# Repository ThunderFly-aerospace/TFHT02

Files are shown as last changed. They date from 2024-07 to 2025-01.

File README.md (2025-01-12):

# TFHT02 - Miniature UAV Humidity and Temperature Sensor



The TFHT02 hygrometer sensor offers flexible integration options. It can be directly connected to a Pixhawk autopilot with PX4 firmware, or it can be used as a sensor for the [TF-ATMON monitoring system](https://www.thunderfly.cz/tf-atmon.html). The TFHT02 is optimized for fast response and reduced sensitivity to solar radiation, making it suitable for meteorological measurements of atmospheric profiles, where rapid environmental changes require fast response to maintain high measurement accuracy.

### Atmospheric sounding

The TFHT02 sensor is designed for [direct atmospheric sounding](https://en.wikipedia.org/wiki/Atmospheric_sounding). Here is an example of measured data taken by [TF-G2 autogyro](https://www.thunderfly.cz/tf-g2.html).

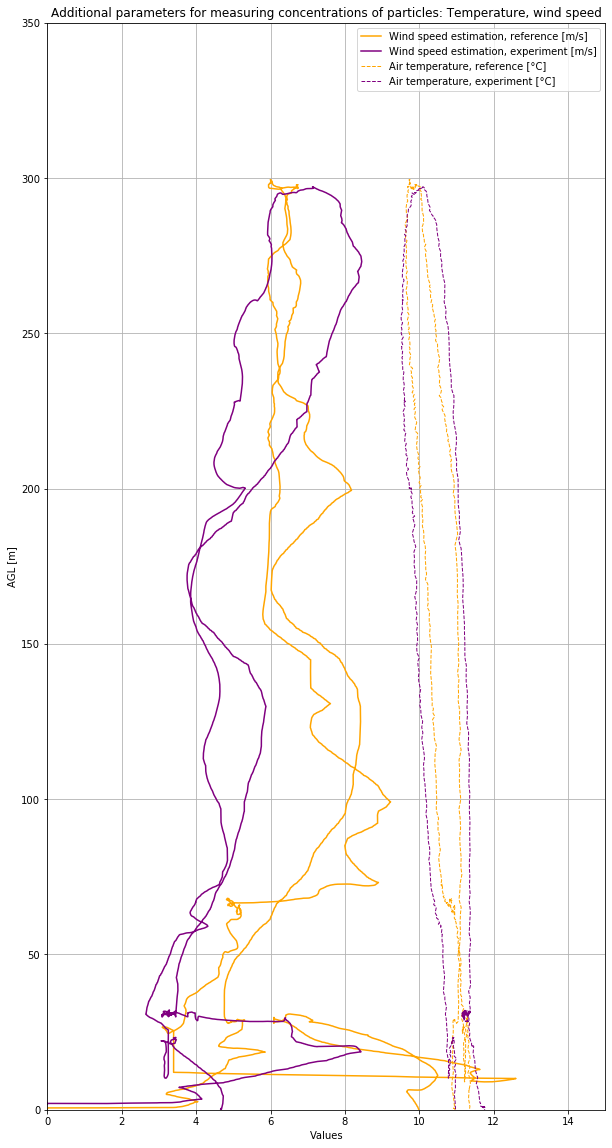
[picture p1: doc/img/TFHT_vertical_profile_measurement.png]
TFHT02A atmospheric profiling


## Where to get it?

The TFHT02 is commercially available from [ThunderFly s.r.o.](https://www.thunderfly.cz/). For a commercial quotation or support, contact us by email at sale@thunderfly.cz or shop at [Tindie store](https://www.tindie.com/products/thunderfly/tfht01-aerial-hygrometer-and-thermometer/).

## Parameters

| Parameter | Value | Description |
|---|---|---|
| Sensing element | [SHT45](https://sensirion.com/media/documents/33FD6951/662A593A/HT_DS_Datasheet_SHT4x.pdf) | Other possible sensors are SHT40 or SHT41 |
| Typical accuracy | 1 %RH and 0.1 °C | |
| Repeatability | 0.15 %RH , 0.08 °C | The stated repeatability is 3 times the standard deviation (3σ) of multiple consecutive measurements at constant ambient conditions. |
| Operating temperature range| 0 °C - +65 °C | Sensor physically measures in range -40°C to +120°C with reduced accuracy |
| Operating humidity range| 0-100 % | At humidity above 80% the performance of the sensor could be degraded in case of prolonged periods |
| I2C connector | 4-pin JST-GH | The second connector could be installed on the opposite side |
| I2C address | 0x44 | |
| Storage temperature range| -20 °C - +40 °C |  |
| Operational input voltage | 3.6 - 5.4V | Overvoltage is internally protected by zener diode |
| Mass | 2 g | PCB without cabling |
| Dimensions | 30 x 15 x 6.5 mm |  PCB |
| Weather resistance | IP40 | External connectors fully occupied. |

## Sensor Design

The TFHT02 sensor is designed with an emphasis on fast response time and minimal sensitivity to solar radiation. This is achieved by reducing the thermal mass around the sensing element, allowing it to rapidly react to changes in ambient conditions. Additionally, the sensor is positioned in a way that maximizes its contact surface with the surrounding airflow, ensuring efficient heat exchange and accurate real-time measurements, which are critical for meteorological applications, especially for atmospheric profiling.

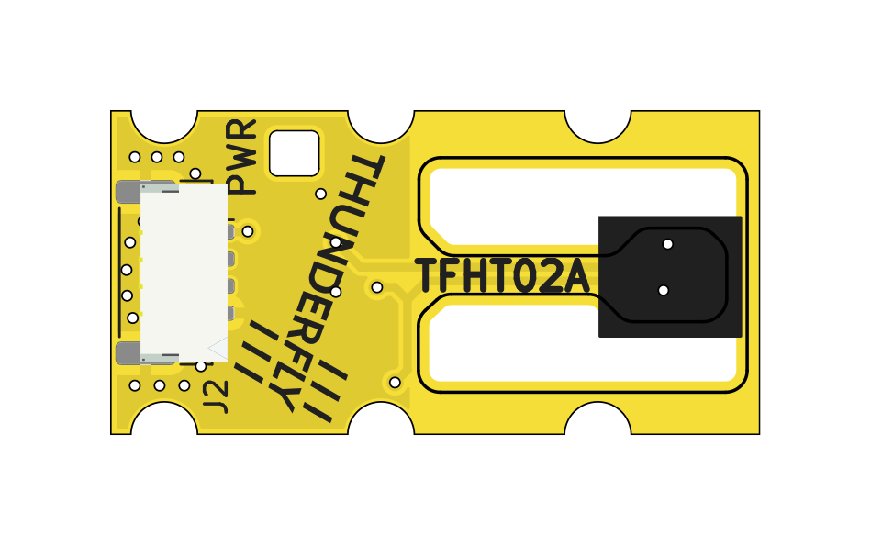
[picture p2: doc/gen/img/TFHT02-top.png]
TFHT02A top view


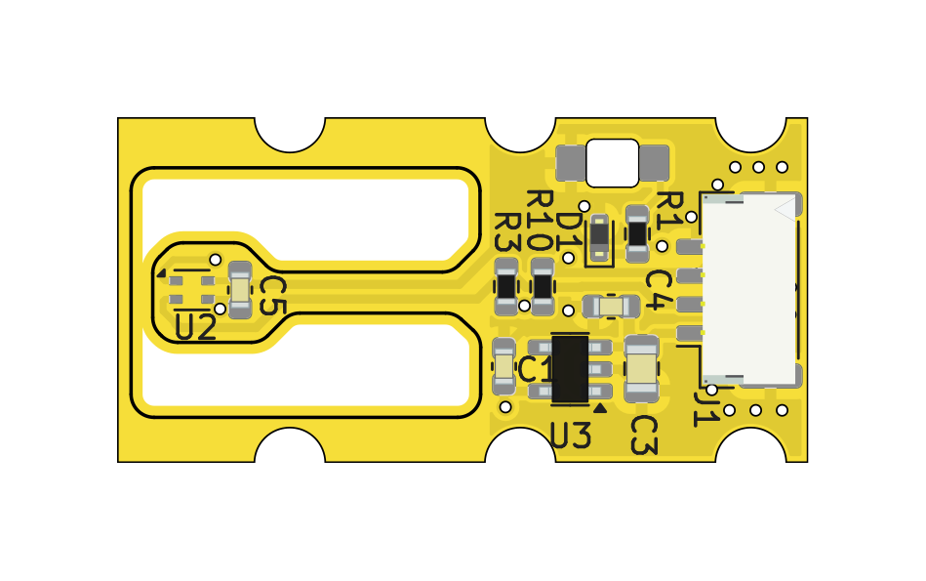
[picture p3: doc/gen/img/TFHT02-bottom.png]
TFHT02A bottom view


### Schematics

Schematics

## Usage in PX4 autopilot firmware

The PX4 autopilot firmware supports the sensor. Multiple sensors can be connected to one autopilot. The measured data could be sent to the ground station and at the same time logged in the onboard ulog file. Sensor support can be enabled by setting the [SENS_EN_SHT4X](http://docs.px4.io/master/en/advanced_config/parameter_reference.html#SENS_EN_SHT3X) parameter to 1.

### Driver Commands Examples

CLI usage example:

    sht4x start -X

Start the sensor driver on the external bus

    sht4x status

Print driver status

    sht4x values

Print the last measured values

    sht4x reset

Reinitialize senzor, reset flags

### PX4 Driver Usage

```
sht4x <command> [arguments...]
 Commands:
   start
     [-I]        Internal I2C bus(es)
     [-X]        External I2C bus(es)
     [-b <val>]  board-specific bus (default=all) (external SPI: n-th bus
                 (default=1))
     [-f <val>]  bus frequency in kHz
     [-q]        quiet startup (no message if no device found)
     [-a <val>]  I2C address
                 default: 68
     [-k]        If initialization (probing) fails, keep retrying periodically

   stop

   status        print status info

   values        Print actual data

   reset         Reinitialize sensor
```

## Usage in Ardupilot firmware

In the Ardupilot firmware, the corresponding sht4x driver for TFHT02 is currently missing. The contributions are welcomed.

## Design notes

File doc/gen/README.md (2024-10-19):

# PCB

Board size: 30.0x15.0 mm (1.18x0.59 inches)

- This is the size of the rectangle that contains the board
- Thickness: 0.89 mm (35 mils)
- Material: FR4
- Finish: HAL lead-free
- Layers: 2
- Copper thickness: 35 µm

Solder mask: TOP / BOTTOM

- Color: Green

Silk screen: TOP / BOTTOM

- Color: White

Stackup:

| Name | Type | Color | Thickness [µm]| Material | Er | Loss tan |
|---|---|---|---|---|---|---|
| F.SilkS | Top Silk Screen | | | | | |
| F.Paste | Top Solder Paste | | | | | |
| F.Mask | Top Solder Mask | Green | 10 | | | |
| F.Cu | copper | | 35 | | | |
| dielectric 1 | core | | 800 | FR4 | 4.5 | 0.020 |
| B.Cu | copper | | 35 | | | |
| B.Mask | Bottom Solder Mask | Green | 10 | | | |
| B.Paste | Bottom Solder Paste  | | | | | |
| B.SilkS | Bottom Silk Screen | | | | | |

# Important sizes

Clearance: 0.2 mm (8 mils)

Track width: 0.3 mm (12 mils)

- By design rules: 0.15 mm (6 mils)

Drill: 0.5 mm (20 mils)

- Vias: 0.5 mm (20 mils) [Design: 0.4 mm (16 mils)]
- Pads: 3.0 mm (118 mils)
- The above values are real drill sizes, they add 0.1 mm (4 mils) to plated holes (PTH)

Via: 0.8/0.4 mm (31/16 mils)

- By design rules: 0.4/0.3 mm (16/12 mils)
- Micro via: yes [0.2/0.1 mm (8/4 mils)]
- Buried/blind via: yes
- Total: 27 (thru: 27 buried/blind: 0 micro: 0)

Outer Annular Ring: 0.15 mm (6 mils)

- By design rules: N/A mm (N/A mils)

Eurocircuits class: 4B
- Using min drill 0.5 mm for an OAR of 0.15 mm

# General stats

Components count: (SMD/THT)

- Top: 1/6 (SMD + THT)
- Bottom: 12/0 (SMD)

Defined tracks:

- 0.3 mm (12 mils)
- 0.4 mm (16 mils)
- 0.5 mm (20 mils)
- 1.0 mm (39 mils)

Used tracks:

- 0.3 mm (12 mils) (15) defined: yes
- 0.4 mm (16 mils) (75) defined: yes
- 0.5 mm (20 mils) (12) defined: yes

Defined vias:

Used vias:

- 0.8/0.4 mm (31/16 mils) (Count: 27, Aspect: 1.1 A) defined: no

Holes (excluding vias):

- 3.0 mm (118 mils) (6)

Oval holes:

Drill tools (including vias and computing adjusts and rounding):

- 0.5 mm (20 mils) (27)
- 3.0 mm (118 mils) (6)

Solder paste stats:

Using a paste with 87.75 % alloy, that has an specific gravity for the alloy of 7.4 g/cm³
and 1.0 g/cm³ for the flux. This paste has an specific gravity of  4.15 g/cm³.

The stencil thickness is  0.12 mm.

| Side | Pads with paste | Area [mm²] | Paste [g] |
|---|---|---|---|
| Top | 6 | 9.28 | 0.05 |
| Bottom | 33 | 30.21 | 0.15 |
| Total  | 39 | 39.48 | 0.20 |

Note: this is just an approximation to the theoretical value. Margins of the solder mask and waste aren't computed.

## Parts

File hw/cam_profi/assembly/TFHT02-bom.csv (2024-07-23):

Component | Description | Part | References | Value | Footprint | Quantity Per PCB | Datasheet | ust_id
1 | Unpolarized capacitor | C | C4C5 | 100nF | C_0603_1608Metric | 2 | ~ | 5c70984812875079b91f8bf2
2 | Unpolarized capacitor | C | C1 | 1uF | C_0603_1608Metric | 1 | ~ | 5c70984812875079b91f8bc2
3 | Unpolarized capacitor | C | C3 | 10uF | C_0805_2012Metric | 1 | ~ | 5c70984812875079b91f8bbd
4 |  | D_ZENER | D1 | BZX585-B5V6.115 | D_SOD-523 | 1 |  | 60879d38128750769ee58e48
5 | Light emitting diode | LED | D2 | LED GREEN | LED_1206_mill | 1 | ~ | 5c70984412875079b91f8895
6 |  | SM04B-GHS-TB | J1J2 | SM04B-GHS-TB | JST_GH_SM04B-GHS-TB_1x04-1MP_P1.25mm_Horizontal | 2 |  | 5c86273d1287500b4e0280be
7 | Resistor | R | R1 | 1k | R_0603_1608Metric | 1 | ~ | 5c70984512875079b91f8957
8 | Resistor | R | R3R10 | 10k | R_0603_1608Metric | 2 | ~ | 5c70984512875079b91f8962
9 | 300mA Low-dropout Voltage Regulator, Vout 3.3V, Vin up to 5.5V, SOT-23 | MIC5504-3.3YM5 | U3 | MIC5504-3.3YM5 | SOT-23-5 | 1 | http://ww1.microchip.com/downloads/en/DeviceDoc/MIC550X.pdf | 5c7255e81287500b4e112ea2
10 | Digital Humidity and Temperature Sensor, +/-1%RH, +/-0.1degC, I2C, 1.08-3.6V, 16bit, DFN-4 | SHT4x | U2 | SHT4x | Sensirion_DFN-4_1.5x1.5mm_P0.8mm_SHT4x_NoCentralPad | 1 | https://www.tme.eu/Document/c90a92e7875700dbf5278abff1cc96dc/SHT4x.pdf | 65227831462c6d9e720559a1

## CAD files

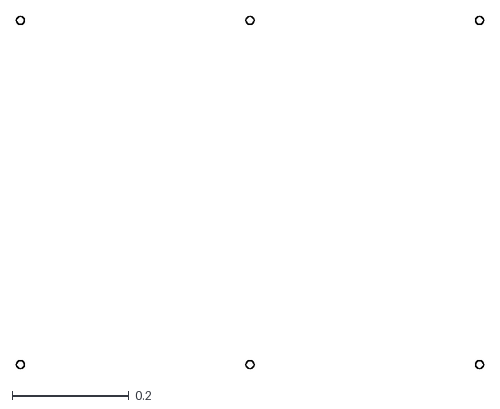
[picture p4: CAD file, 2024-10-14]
doc/gen/dxf/TFHT02-Margin.dxf
0.801 x 0.604

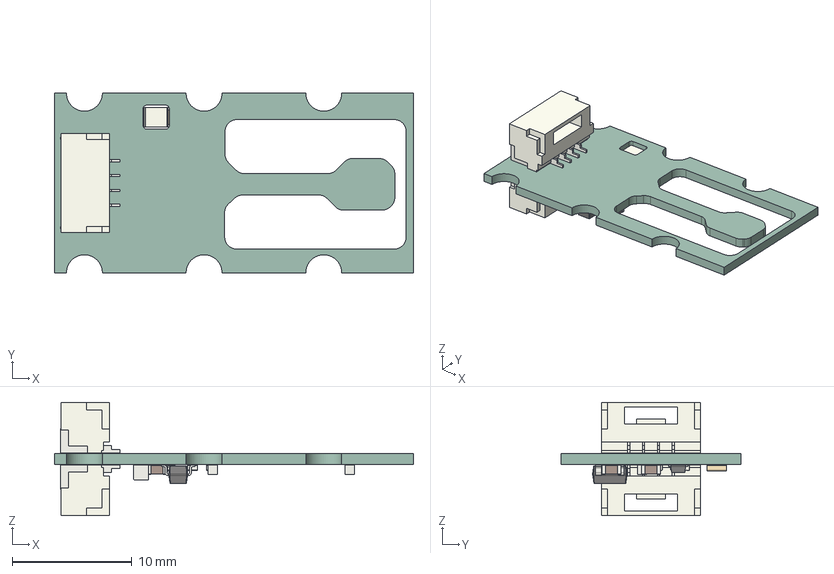
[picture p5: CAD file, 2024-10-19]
doc/gen/TFHT02.step
30.0 x 15.0 x 9.48 mm
JST_SM04B_GHS_TB x 2
LED_1206_3216Metric
C_0603_1608Metric x 3
D_SOD_523
C_0805_2012Metric
SOT_23_5
R_0603_1608Metric x 3
kibot_bdm0kd_t_PCB

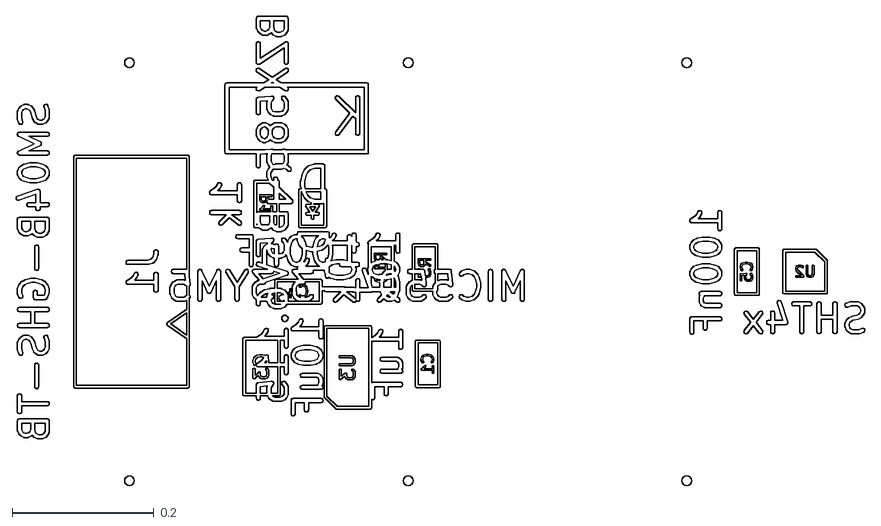
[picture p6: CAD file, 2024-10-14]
doc/gen/dxf/TFHT02-B_Fab.dxf
1.20 x 0.663

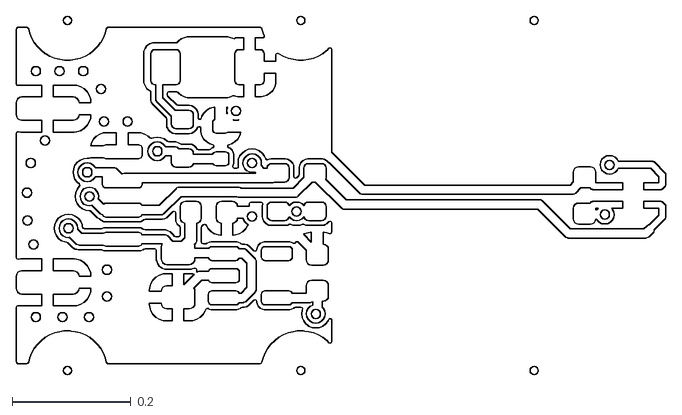
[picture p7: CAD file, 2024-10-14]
doc/gen/dxf/TFHT02-B_Cu.dxf
1.10 x 0.604

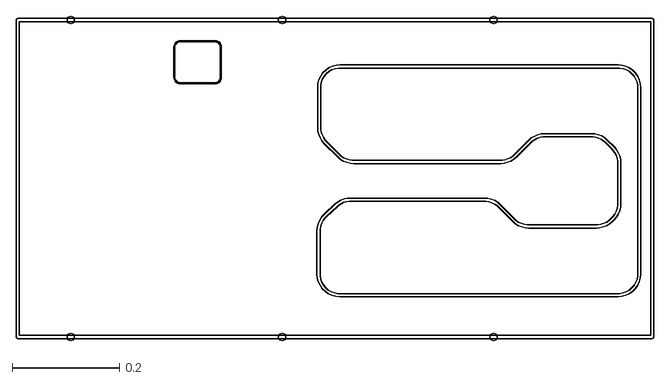
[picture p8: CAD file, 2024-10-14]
doc/gen/dxf/TFHT02-Edge_Cuts.dxf
1.19 x 0.604

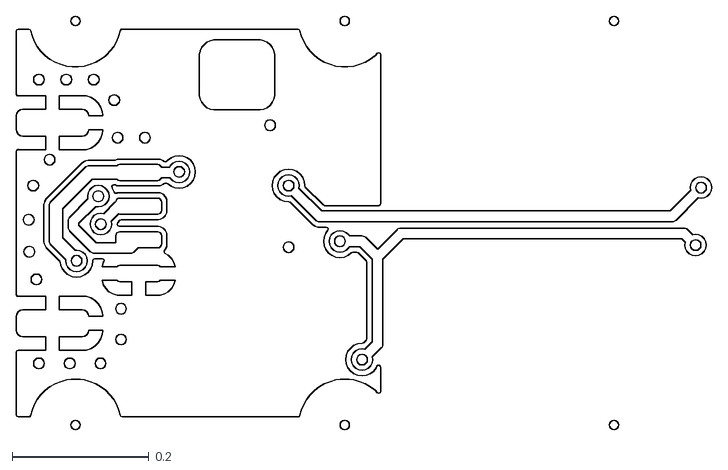
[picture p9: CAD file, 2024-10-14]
doc/gen/dxf/TFHT02-F_Cu.dxf
1.02 x 0.604

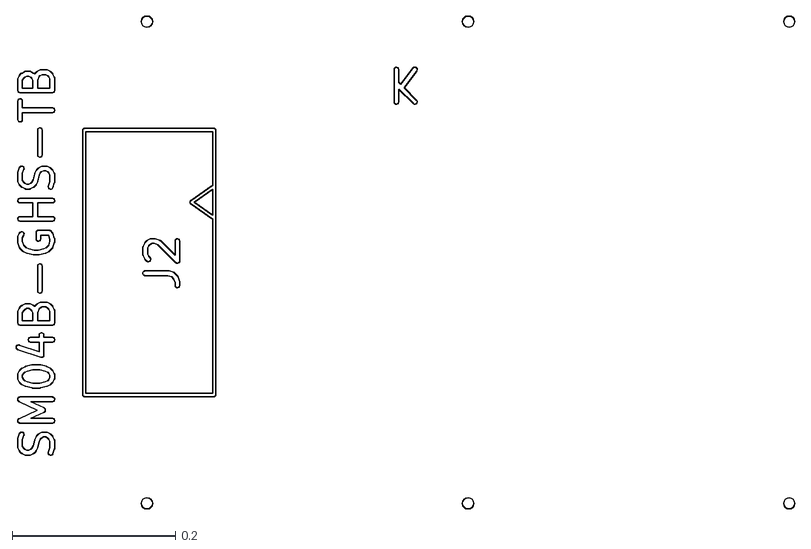
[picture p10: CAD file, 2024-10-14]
doc/gen/dxf/TFHT02-F_Fab.dxf
0.955 x 0.604

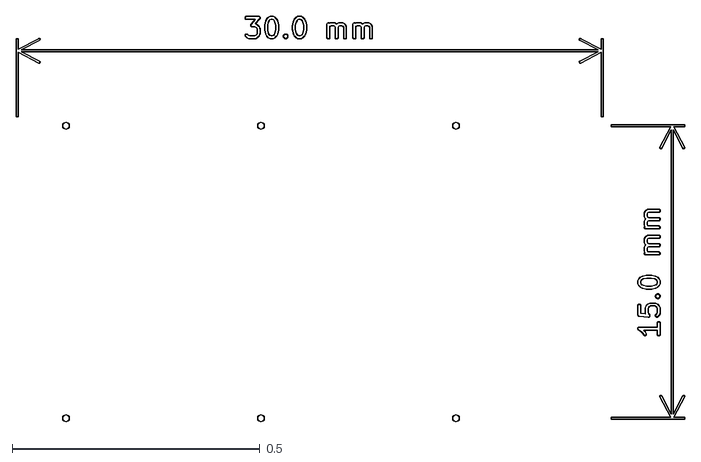
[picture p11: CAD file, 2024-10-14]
doc/gen/dxf/TFHT02-User_Drawings.dxf
1.35 x 0.818

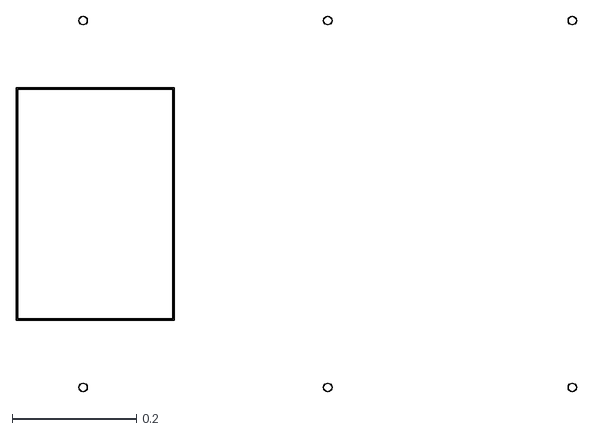
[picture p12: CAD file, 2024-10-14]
doc/gen/dxf/TFHT02-F_Courtyard.dxf
0.902 x 0.604

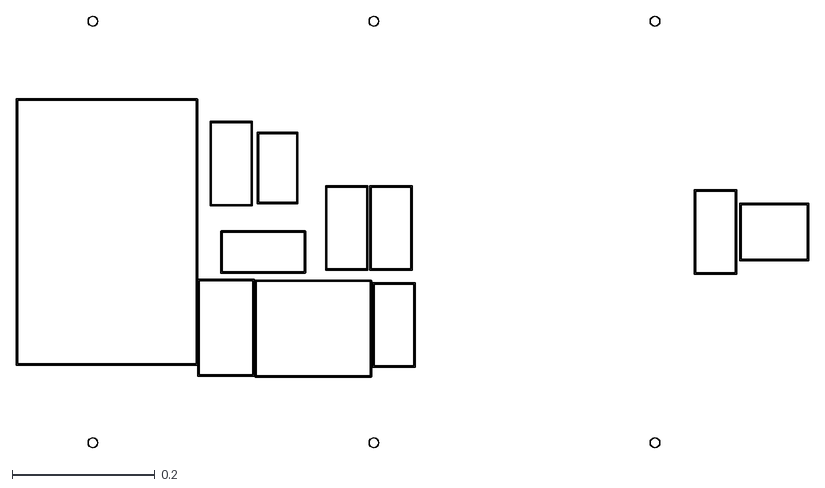
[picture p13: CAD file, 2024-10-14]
doc/gen/dxf/TFHT02-B_Courtyard.dxf
1.11 x 0.604

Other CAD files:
doc/TFHT02.step
doc/gen/dxf/TFHT02-B_Mask.dxf
doc/gen/dxf/TFHT02-B_Paste.dxf
doc/gen/dxf/TFHT02-B_Silkscreen.dxf
doc/gen/dxf/TFHT02-F_Mask.dxf
doc/gen/dxf/TFHT02-F_Paste.dxf
doc/gen/dxf/TFHT02-F_Silkscreen.dxf

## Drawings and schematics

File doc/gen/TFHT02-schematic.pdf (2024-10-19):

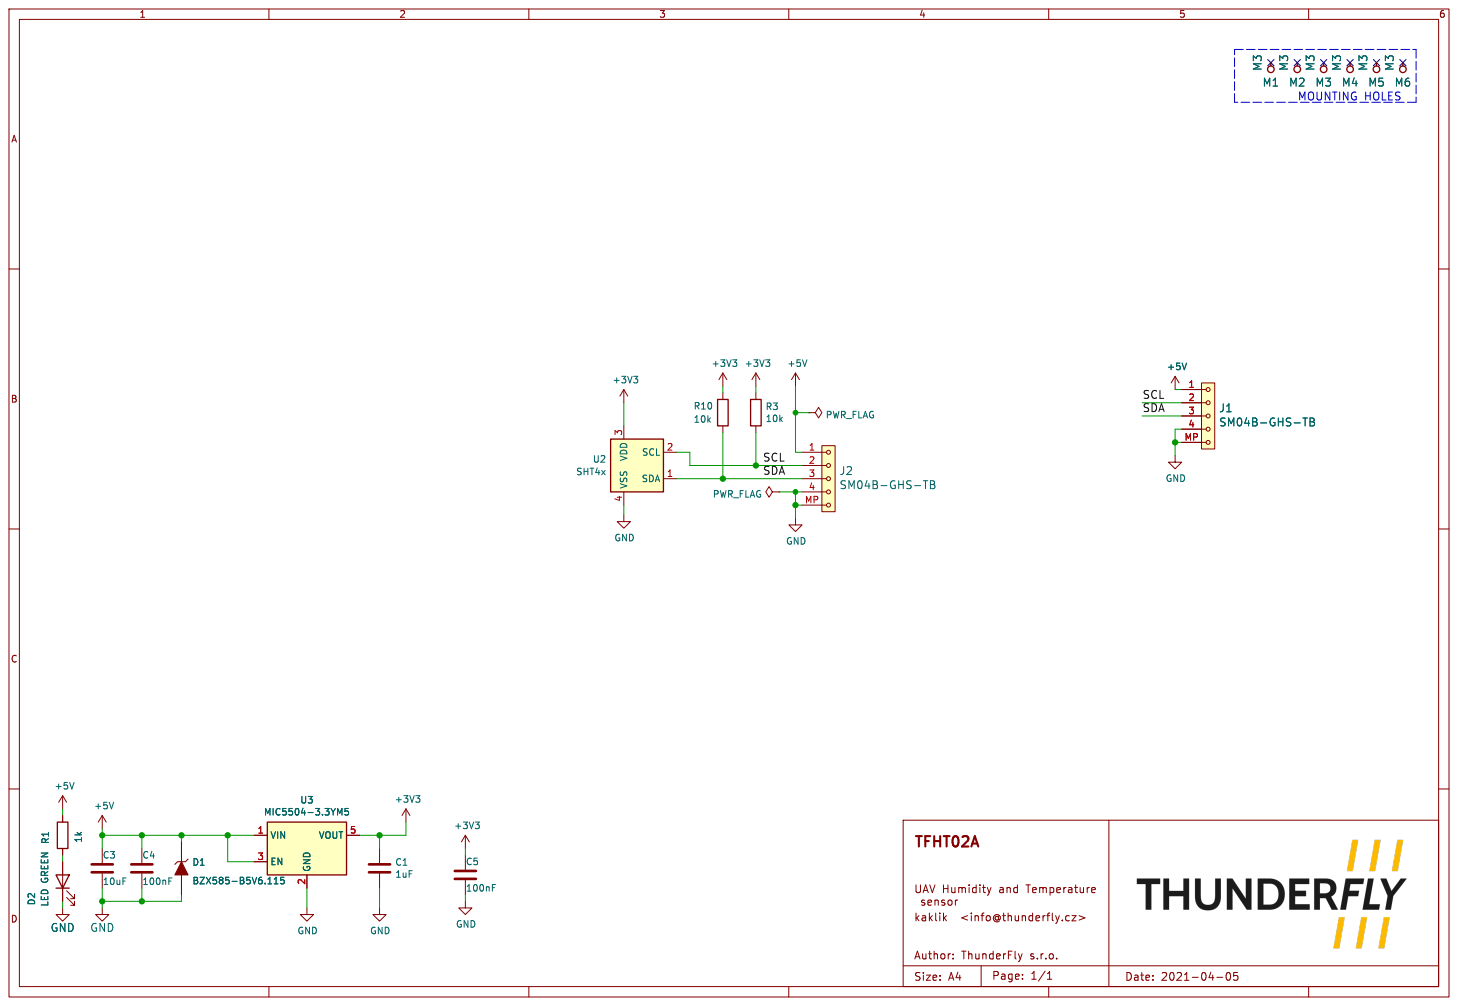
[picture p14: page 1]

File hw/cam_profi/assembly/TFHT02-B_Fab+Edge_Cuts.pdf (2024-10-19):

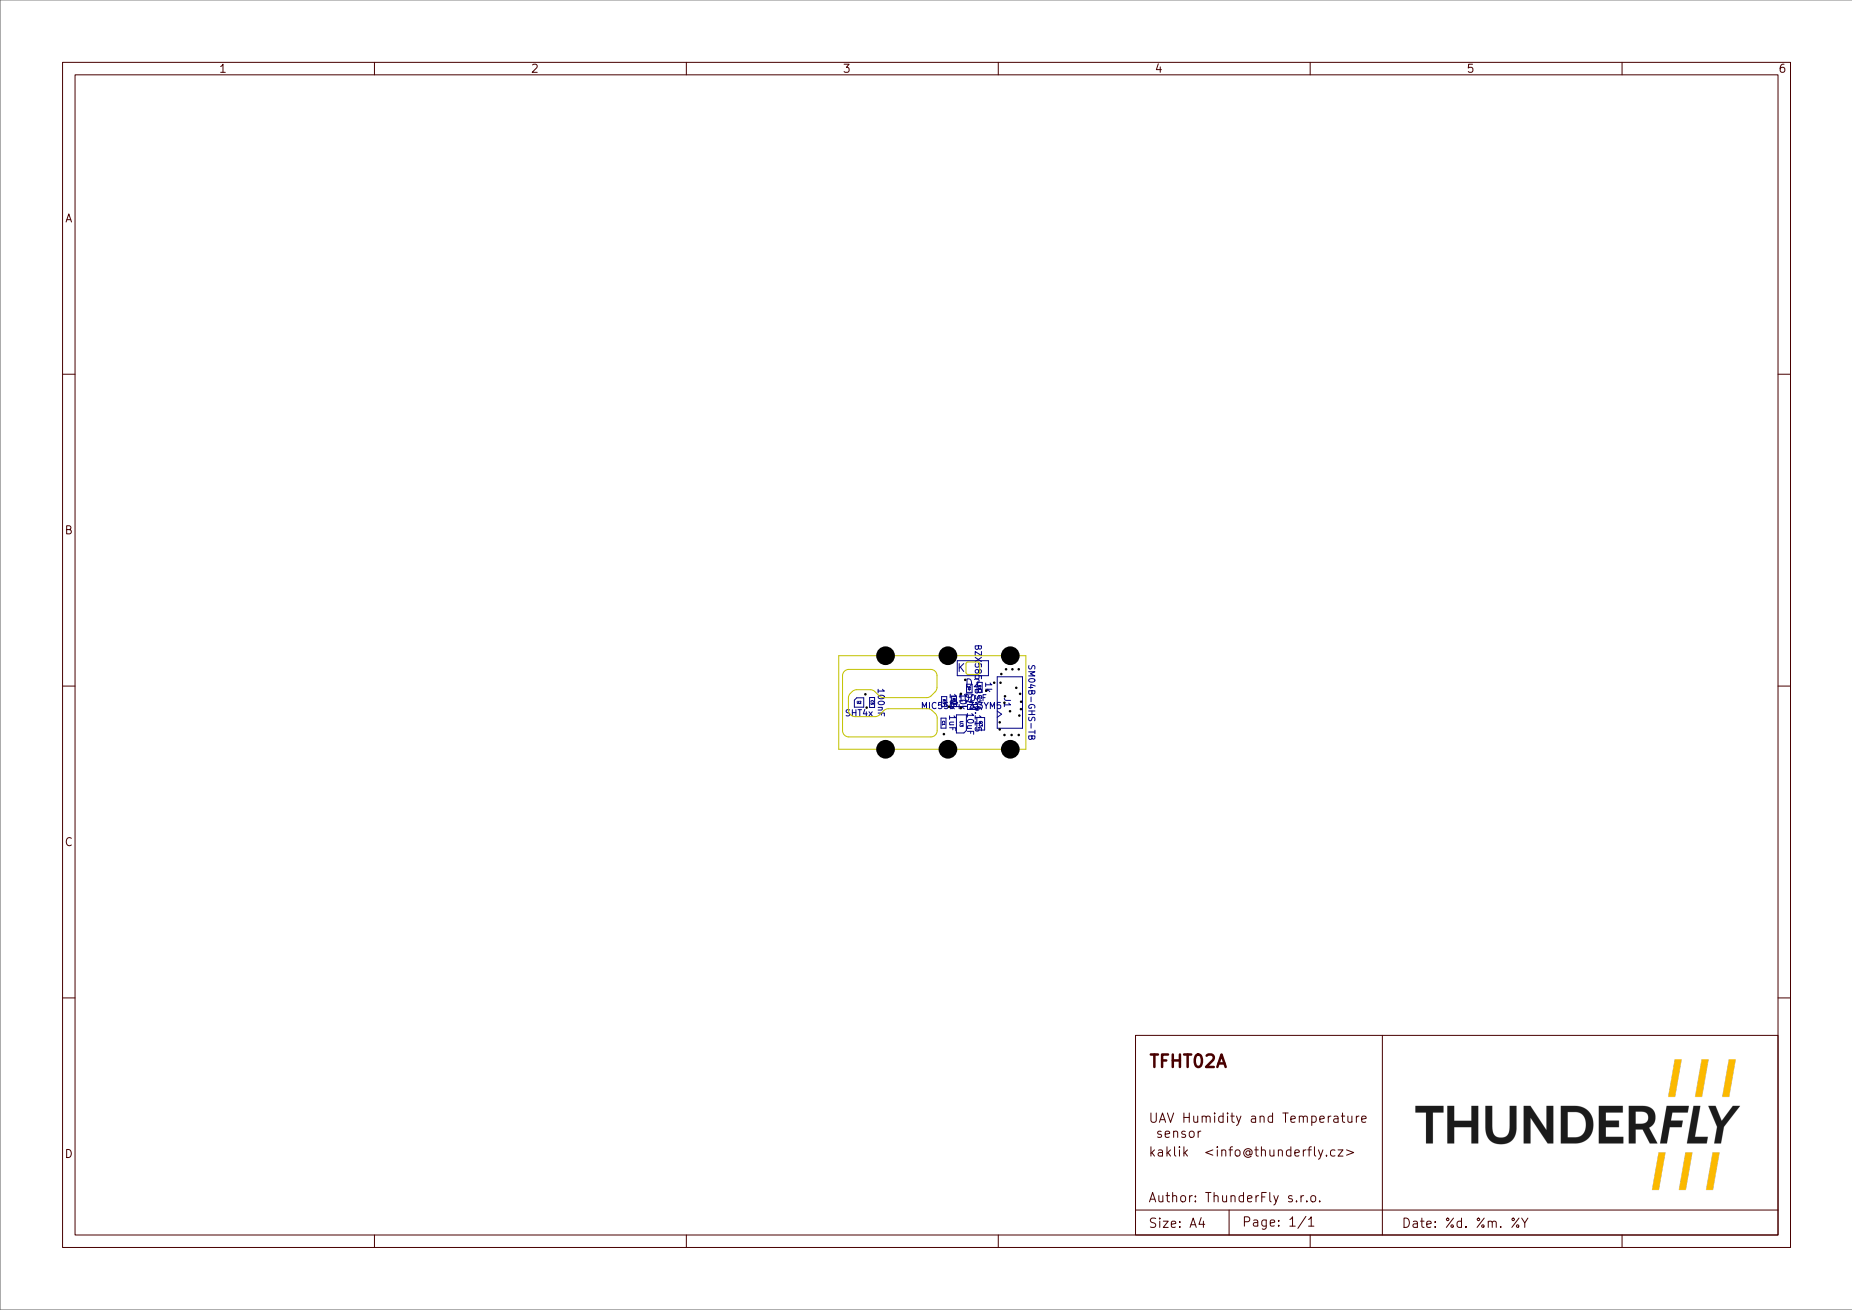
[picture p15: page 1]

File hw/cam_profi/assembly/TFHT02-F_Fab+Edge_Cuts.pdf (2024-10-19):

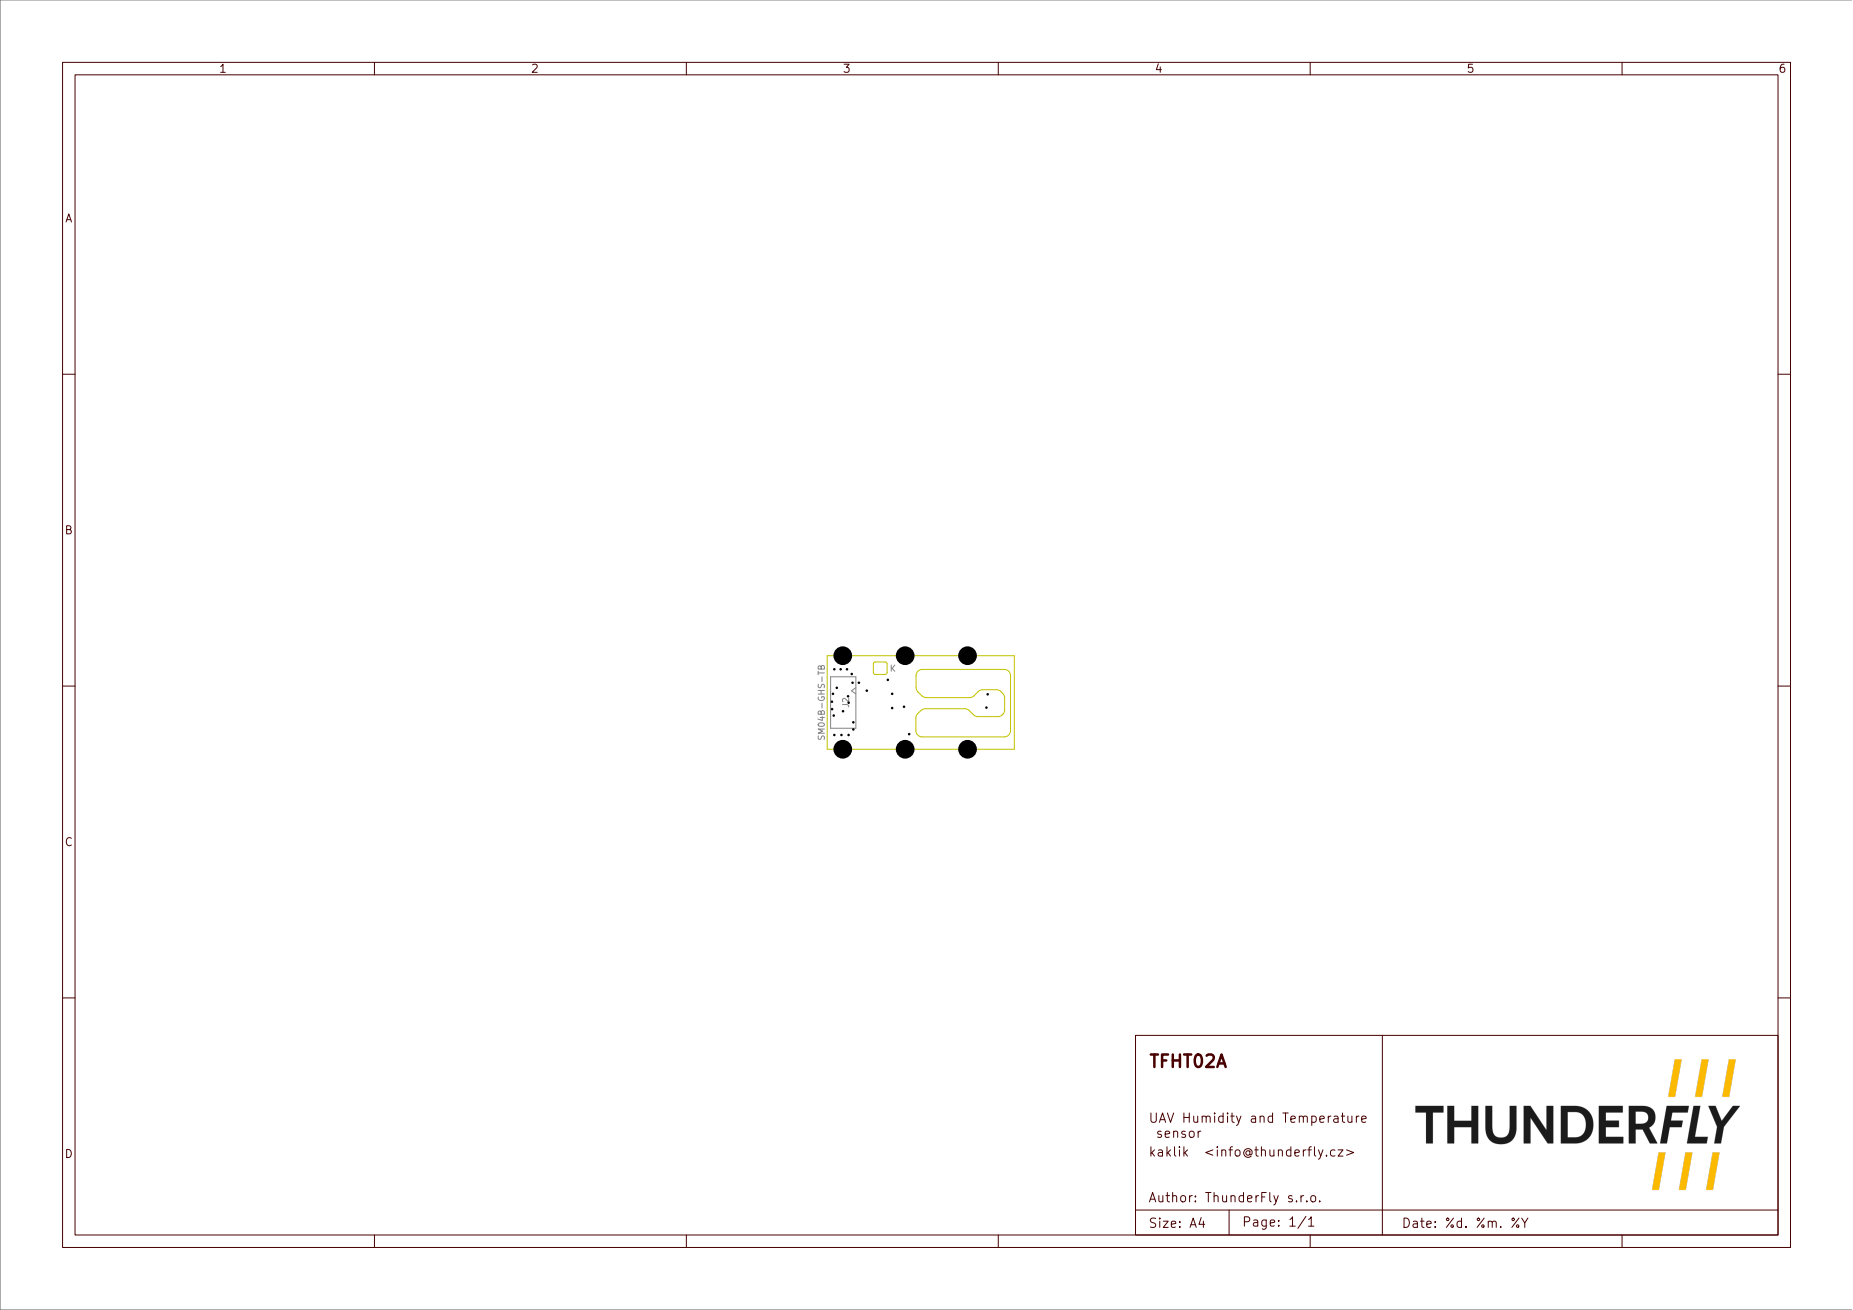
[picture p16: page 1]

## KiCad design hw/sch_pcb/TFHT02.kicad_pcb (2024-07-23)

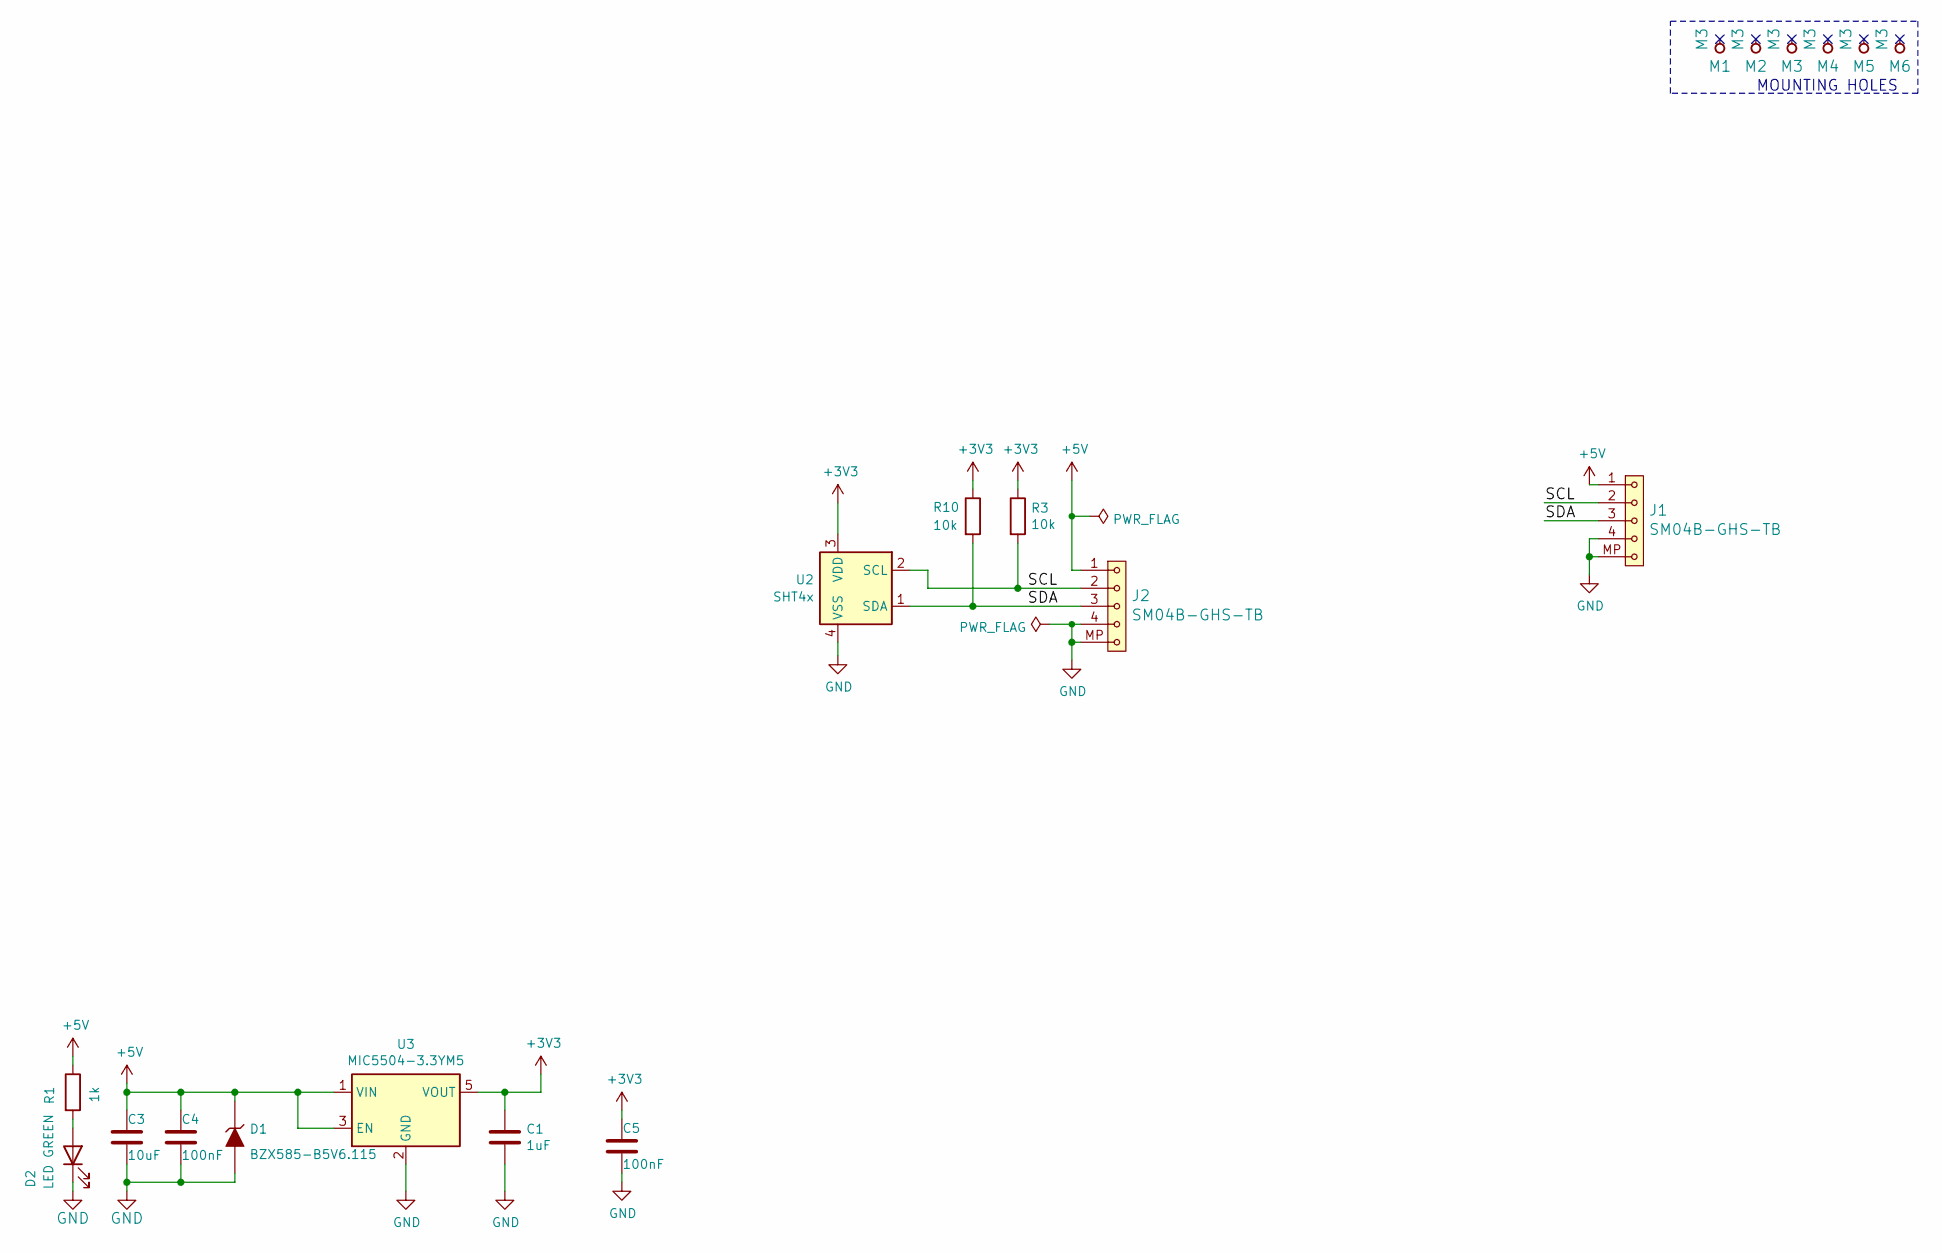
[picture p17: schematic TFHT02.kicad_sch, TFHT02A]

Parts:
C1: 1uF; C_0603_1608Metric
C3: 10uF; C_0805_2012Metric
C4, C5: 100nF; C_0603_1608Metric
D1: BZX585-B5V6.115; D_SOD-523
D2: LED GREEN; LED_1206_mill
J1, J2: SM04B-GHS-TB; JST_GH_SM04B-GHS-TB_1x04-1MP_P1.25mm_Horizontal
M1, M2, M3, M4, M5, M6: M3; dira_3mm
R1: 1k; R_0603_1608Metric
R3, R10: 10k; R_0603_1608Metric
U2: SHT4x; Sensirion_DFN-4_1.5x1.5mm_P0.8mm_SHT4x_NoCentralPad
U3: MIC5504-3.3YM5; SOT-23-5

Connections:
+3V3: C1.1, C5.1, R3.1, R10.1, U2.3 (VDD), U3.5 (VOUT)
+5V: C3.1, C4.1, D1.1 (K), J1.1, J2.1, R1.1, U3.1 (VIN), U3.3 (EN)
/SCL: J1.2, J2.2, R3.2, U2.2 (SCL)
/SDA: J1.3, J2.3, R10.2, U2.1 (SDA)
GND: C1.2, C3.2, C4.2, C5.2, D1.2 (A), D2.1 (K), J1.4, J1.MP, J2.4, J2.MP, U2.4 (VSS), U3.2 (GND)
unnamed: D2.2 (A), R1.2

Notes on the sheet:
MOUNTING HOLES

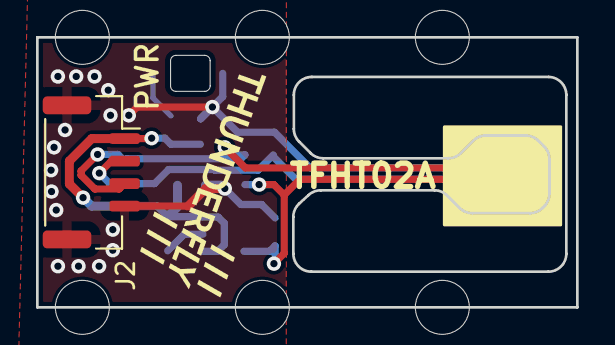
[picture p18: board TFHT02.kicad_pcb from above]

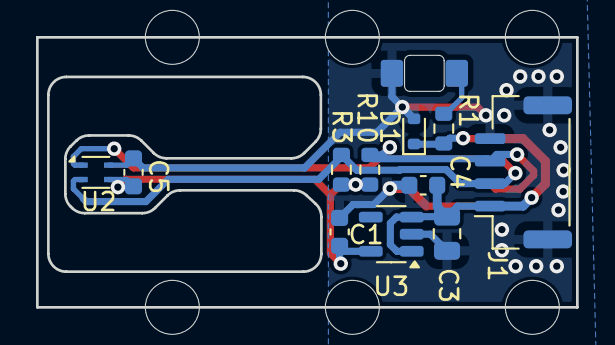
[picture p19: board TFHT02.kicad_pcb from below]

Board: 2 copper layers, 30.0 x 15.0 mm, 19 parts (12 on the bottom side), 6 nets.

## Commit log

2024-07-23 The firstly routed PCB with rought outline.
    [TFHT01.kicad_pcb, TFHT01.kicad_sch, TFHT02.kicad_pcb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]
2024-07-23 Improved layout and geometry.
    [TFHT02.kicad_pcb]
2024-07-23 Fillet radius of internal slot.
    [TFHT02.kicad_pcb]
2024-07-23 Updating KiCAD actions.
2024-07-23 Update actions products
    [TFHT01-B_Courtyard.dxf, TFHT01-B_Cu.dxf, TFHT01-B_Fab.dxf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]
2024-09-10 add step file
    [TFHT02.step]
2025-01-12 Update driver name in readme.
